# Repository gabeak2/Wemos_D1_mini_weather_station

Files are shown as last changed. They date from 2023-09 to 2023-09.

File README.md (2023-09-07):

# Wemos_D1_mini_weather_station
Mini weather station built around ESP8266 WiFi SOC on a Wemos D1-Mini breakout PCB.  Shows inside temperature and wifi-updated outside temp, and has LED to indicate for rain.




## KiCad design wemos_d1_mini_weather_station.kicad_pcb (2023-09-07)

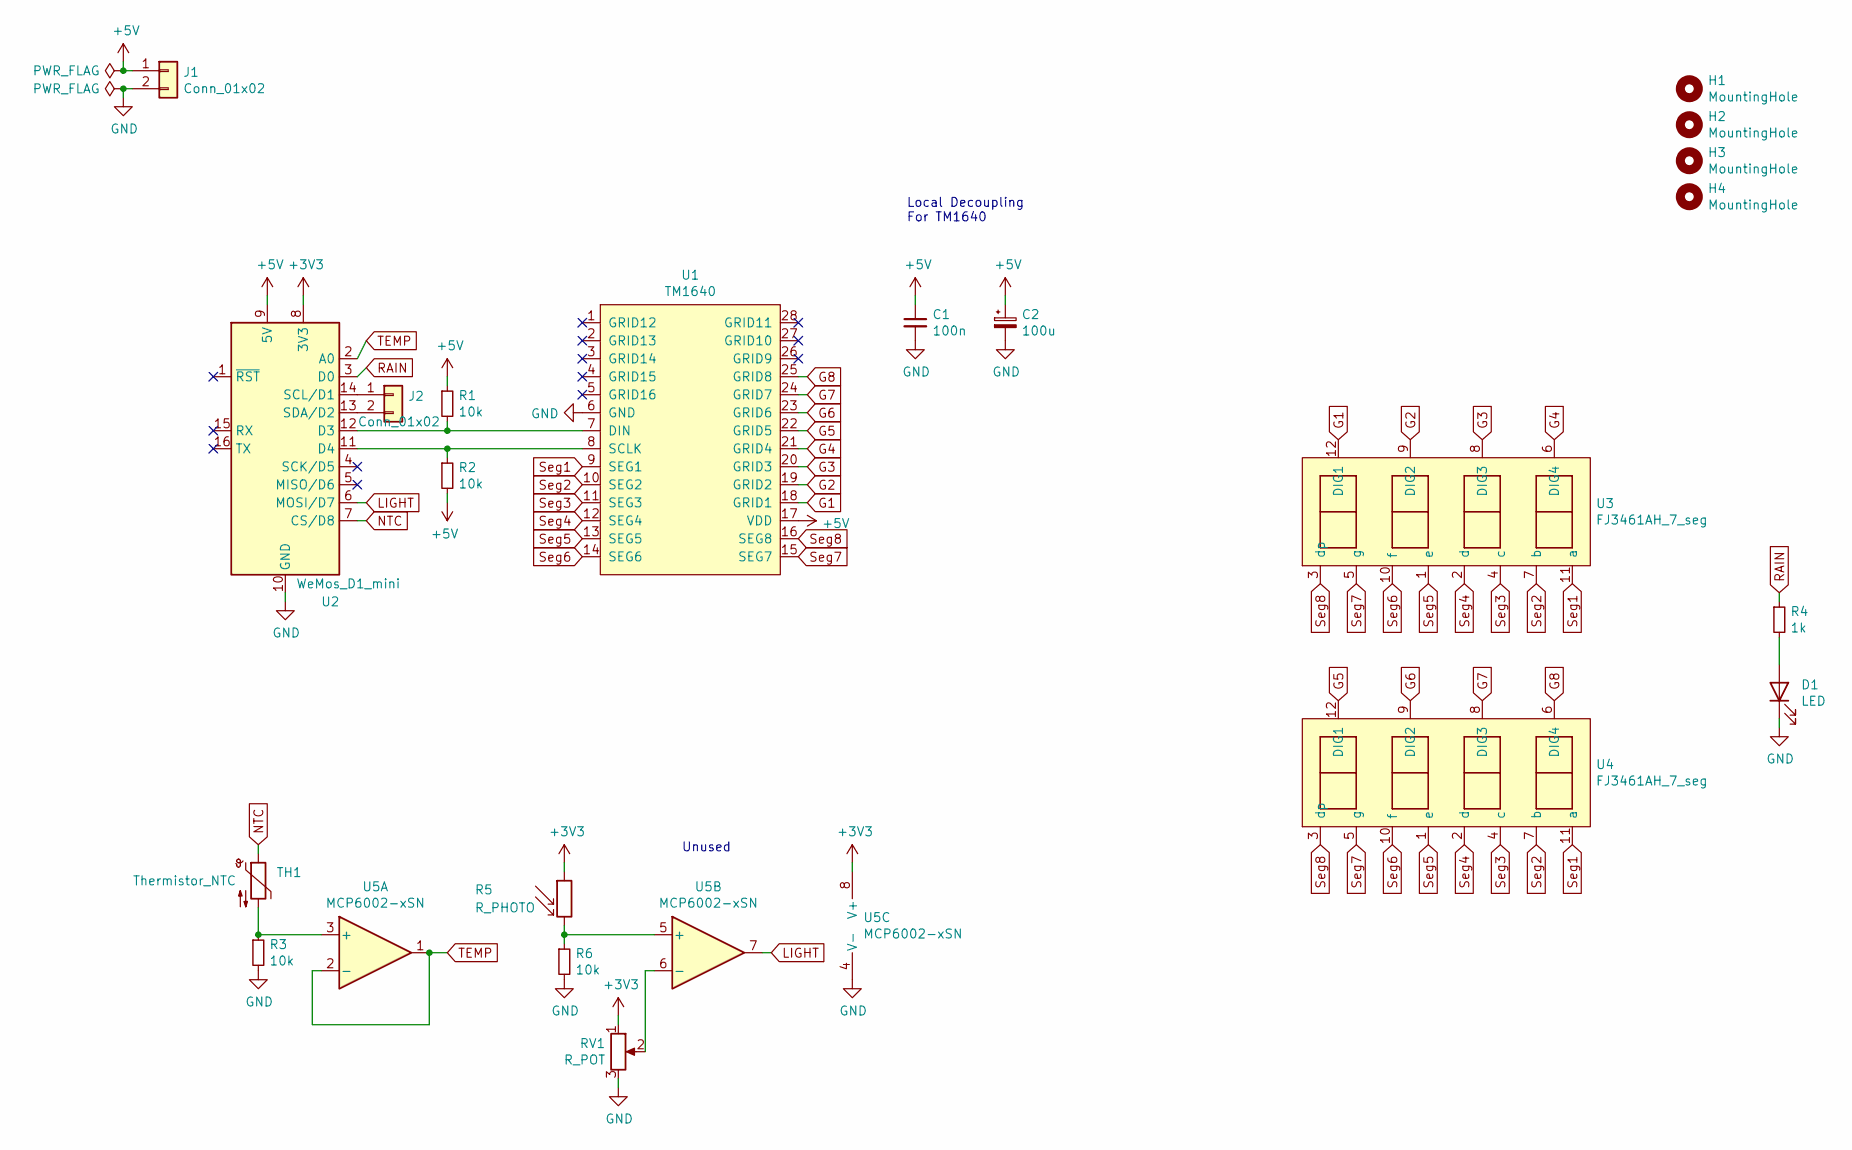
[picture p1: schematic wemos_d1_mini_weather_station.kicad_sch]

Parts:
C1: 100n; C_0805_2012Metric
C2: 100u; CP_EIA-7343-31_Kemet-D
D1: LED; LED_D5.0mm
H1, H2, H3, H4: MountingHole; MountingHole_3.2mm_M3
J1, J2: Conn_01x02; PinSocket_1x02_P2.54mm_Vertical
R1, R2, R3, R6: 10k; R_0805_2012Metric
R4: 1k; R_0805_2012Metric
R5: R_PHOTO; PinSocket_1x02_P2.54mm_Vertical
RV1: R_POT; Potentiometer_Bourns_3266Y_Vertical
TH1: Thermistor_NTC; PinSocket_1x02_P2.54mm_Vertical
U1: TM1640; SOIC-28W_7.5x17.9mm_P1.27mm
U2: WeMos_D1_mini; WEMOS_D1_mini_light
U3, U4: FJ3461AH_7_seg; FJ3461AH
U5: MCP6002-xSN; SOIC-8_3.9x4.9mm_P1.27mm

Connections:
+3V3: R5.1, RV1.1, U2.8 (3V3), U5.8 (V+)
+5V: C1.1, C2.1, J1.1, R1.1, R2.2, U1.17 (VDD), U2.9 (5V); also elsewhere on the board
G1: U1.18 (GRID1), U3.12 (DIG1)
G2: U1.19 (GRID2), U3.9 (DIG2)
G3: U1.20 (GRID3), U3.8 (DIG3)
G4: U1.21 (GRID4), U3.6 (DIG4)
G5: U1.22 (GRID5), U4.12 (DIG1)
G6: U1.23 (GRID6), U4.9 (DIG2)
G7: U1.24 (GRID7), U4.8 (DIG3)
G8: U1.25 (GRID8), U4.6 (DIG4)
GND: C1.2, C2.2, D1.1 (K), J1.2, R3.2, R6.2, RV1.3, U1.6 (GND), U2.10 (GND), U5.4 (V-); also elsewhere on the board
LIGHT: U2.6 (MOSI/D7), U5.7
NTC: TH1.1, U2.7 (CS/D8)
unnamed: D1.2 (A), R4.2
unnamed 14: J2.1, U2.14 (SCL/D1); also elsewhere on the board
unnamed 15: J2.2, U2.13 (SDA/D2); also elsewhere on the board
unnamed: R1.2, U1.7 (DIN), U2.12 (D3)
unnamed: R2.1, U1.8 (SCLK), U2.11 (D4)
unnamed: R3.1, TH1.2, U5.3 (+)
unnamed: R5.2, R6.1, U5.5 (+)
unnamed: RV1.2, U5.6 (-)
RAIN: R4.1, U2.3 (D0)
Seg1: U1.9 (SEG1), U3.11 (a), U4.11 (a)
Seg2: U1.10 (SEG2), U3.7 (b), U4.7 (b)
Seg3: U1.11 (SEG3), U3.4 (c), U4.4 (c)
Seg4: U1.12 (SEG4), U3.2 (d), U4.2 (d)
Seg5: U1.13 (SEG5), U3.1 (e), U4.1 (e)
Seg6: U1.14 (SEG6), U3.10 (f), U4.10 (f)
Seg7: U1.15 (SEG7), U3.5 (g), U4.5 (g)
Seg8: U1.16 (SEG8), U3.3 (dp), U4.3 (dp)
TEMP: U2.2 (A0), U5.1, U5.2 (-)

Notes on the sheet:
Local Decoupling For TM1640
Unused

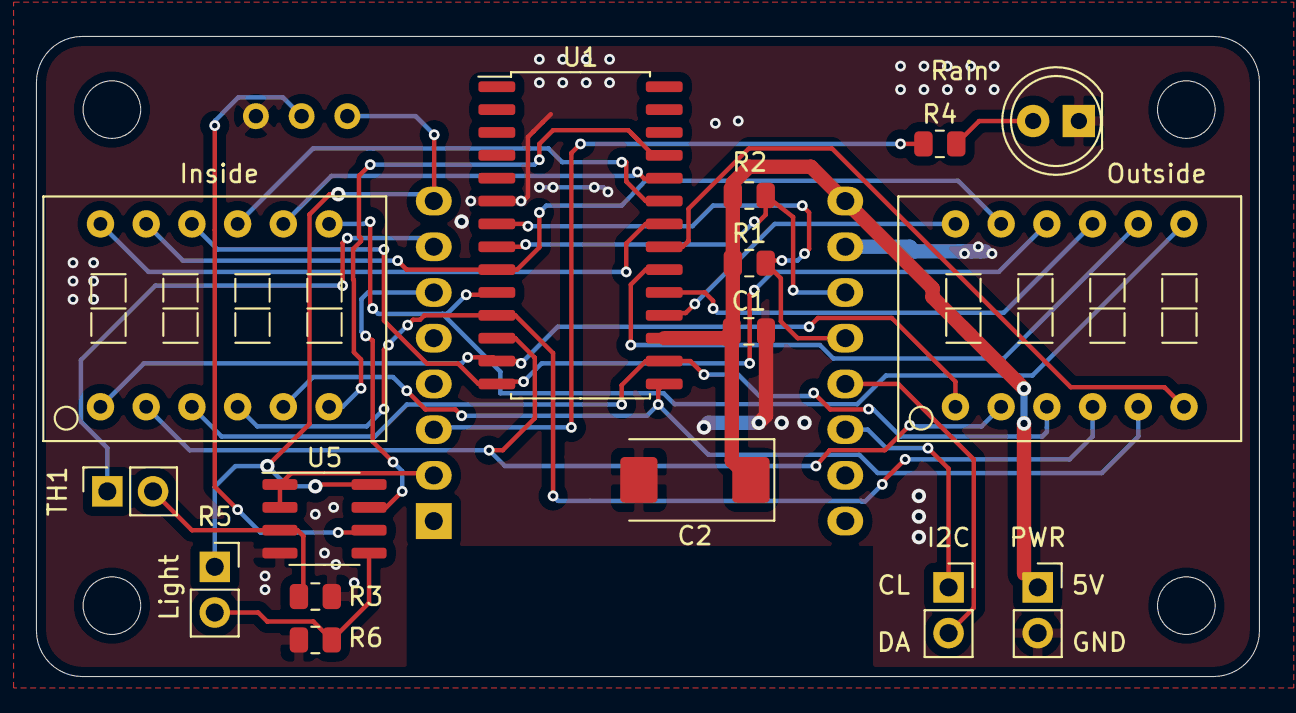
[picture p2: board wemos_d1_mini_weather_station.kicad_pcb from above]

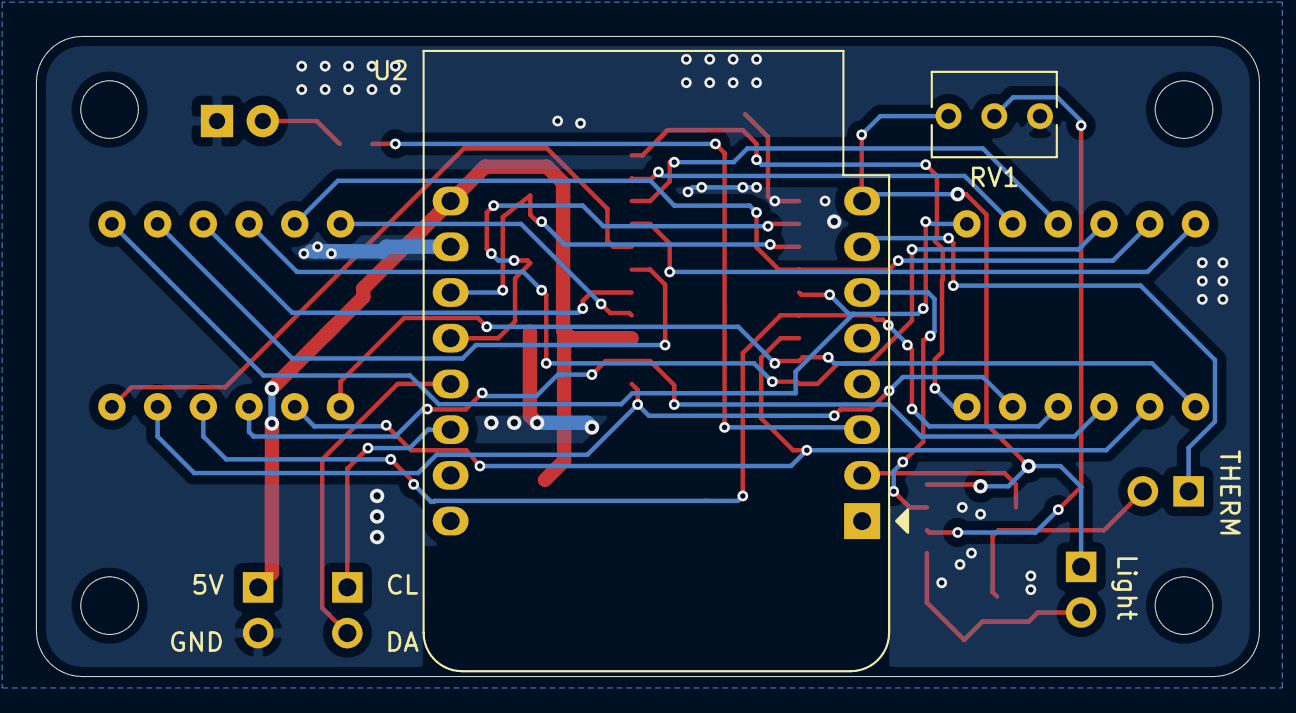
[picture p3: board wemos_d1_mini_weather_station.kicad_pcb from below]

Board: 2 copper layers, 67.9 x 35.6 mm, 22 parts (2 on the bottom side), 31 nets.

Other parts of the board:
I2C: Conn_01x02; PinSocket_1x02_P2.54mm_Vertical
PWR: Conn_01x02; PinSocket_1x02_P2.54mm_Vertical

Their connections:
+5V: PWR.1; also elsewhere on the board
GND: PWR.2; also elsewhere on the board
unnamed 14: I2C.1; also elsewhere on the board
unnamed 15: I2C.2; also elsewhere on the board

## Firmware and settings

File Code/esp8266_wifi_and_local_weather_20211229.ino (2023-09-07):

#include <WiFiManager.h>
#include <WiFiClient.h>
#include <ESP8266WiFi.h>
#include <ESP8266HTTPClient.h>
#include <ArduinoJson.h>
#include <TM1640.h>

#define RAINLED D0
#define SDA D3 
#define SCL D4 
#define NTC D8
#define FUDGE 0
#define BRIGHTNESS 7

String open_weather_key = "9ca5c5c97ba38f517f7a22d15dd29749";
String city = "Santa Cruz";
String state_code = "CA";
String country_code = "US";

String server_path = "http://api.openweathermap.org/data/2.5/weather?q=" + city + "," + state_code + "," + country_code + "&units=imperial&APPID=" + open_weather_key;

float cur_temp;
float last_temp;
float outside_temp;

WiFiClient client;
TM1640 module(SDA,SCL,8);    // data, clock, 4 digits

//define functions
void wm_setup();
double temp_from_adc();
float make_http_request();
bool wifi_good = 0;
bool rainbool = 0;

WiFiManager wm;

void setup() {
  Serial.begin(115200);
  module.setupDisplay(true, BRIGHTNESS);
  pinMode(NTC, OUTPUT);
  cur_temp = temp_from_adc();
  wm_setup(); //set up WiFiManager - captive portal, etc.  
  pinMode(SDA,OUTPUT);
  pinMode(SCL,OUTPUT);
  pinMode(RAINLED, OUTPUT);
}

void loop() {
  // put your main code here, to run repeatedly:
  outside_temp = make_http_request();
  Serial.println(outside_temp);

  for(int i = 0; i < 200; i++){
    last_temp = cur_temp;
    cur_temp = temp_from_adc();
    cur_temp = (last_temp * 199.0 + cur_temp)/200.0; //weighted average to move slowly in presence of noise
    display_temps(cur_temp,outside_temp);
    Serial.println(cur_temp);
    delay(1000);
  }
//  delay(20000);
}

float make_http_request(){
  HTTPClient http;
  http.begin(client, server_path);
  int httpCode = http.GET();

  DynamicJsonDocument doc(2048);
  deserializeJson(doc, http.getStream());

  String rain = "Rain";
  String drizzle = "Drizzle";
  String thunderstorm = "Thunderstorm";
  String mist = "Mist";
  String snow = "Snow";
  
  if(rain.equals(doc["weather"][0]["main"].as<String>())){
    rainbool = 1;
  }
  else if(drizzle.equals(doc["weather"][0]["main"].as<String>())){
    rainbool = 1;
  }
  else if(thunderstorm.equals(doc["weather"][0]["main"].as<String>())){
    rainbool = 1;
  }
  else if(mist.equals(doc["weather"][0]["main"].as<String>())){
    rainbool = 1;
  }
  else if(snow.equals(doc["weather"][0]["main"].as<String>())){
    rainbool = 1;
  }
  else{
    rainbool = 0;
  }

  digitalWrite(RAINLED, rainbool);

  return doc["main"]["temp"].as<float>();
  http.end();
}

void display_temps(float inside_temp, float outside_temp){

  float temp = inside_temp;
  int hundreds = ((int)temp)/100;
  int tens = ( ((int)temp) % 100)/10;
  int ones = ((int)temp) % 10;
  int tenths = ( ((int)(temp*10))%10 );
  int nums[] = {hundreds,tens,ones,tenths};
  for(int i = 4 ; i < 8; i++){
//    Serial.println(nums[i-4]);
    if(i == 4){
      if(nums[i-4] != 0){
        module.setDisplayDigit(nums[i-4],i,false);
      }
      //else don't add leading 0
    }
    else if(i == 6){
      module.setDisplayDigit(nums[i-4],i,true);
    }
    else{
      module.setDisplayDigit(nums[i-4],i,false);
    }
  }

  temp = outside_temp;
  nums[0] = ((int)temp)/100;
  nums[1] = ( ((int)temp) % 100)/10;
  nums[2] = ((int)temp) % 10;
  nums[3] = ( ((int)(temp*10))%10 );

  for(int i = 0 ; i < 4; i++){
//    Serial.println(nums[i]);
    if(i == 0){
      if(nums[i] != 0){
        module.setDisplayDigit(nums[i],i,false);
      }
      //else don't display leading 0
    }
    else if(i == 2){
      module.setDisplayDigit(nums[i],i,true);
    }
    else{
      module.setDisplayDigit(nums[i],i,false);
    }
  }

  
}

double temp_from_adc(){
  //using coeffs from a 3rd order polynomial fit, calculate celcius temp
  //1.31350623e-07, -1.76328492e-04,  1.66228069e-01, -3.14308794e+01
  digitalWrite(NTC,HIGH);
  delay(50); //settling time
//  module.setupDisplay(false, BRIGHTNESS);
  long int tbuf = 0;
  int adc_vals[1000] = {0};
  for(int i = 0; i < 1000; i++){
    adc_vals[i] = (analogRead(A0)-1)*489/522;
    tbuf += adc_vals[i];
//    Serial.println(adc_vals[i]);
    delay(2);
  }

  
  module.setupDisplay(true, BRIGHTNESS);
  digitalWrite(NTC,LOW);
  double adc_val = tbuf/1000.0;
//  Serial.println(adc_val);
  double celcius_temp = -3.14308794*10 + (adc_val * 0.16622806) + (adc_val*adc_val * -.000176328492) + 
                      (adc_val*adc_val*adc_val*0.000000131351);
  double fahrenheit_temp = (celcius_temp * 1.8) + 32.0;
  return fahrenheit_temp - FUDGE;
}

void wm_setup(){
  //Sets up captive portal to use phone to connect to wifi
  //search for "APconnect" wifi network
  WiFi.mode(WIFI_STA);
//  WiFiManager wm; //wifi manager for phones to connect things
//  wm.resetSettings(); // to reset and re-connect through portal
  wm.setConfigPortalBlocking(true);
  wifi_good = wm.autoConnect("AutoConnectAP","password"); // password protected ap  
}
